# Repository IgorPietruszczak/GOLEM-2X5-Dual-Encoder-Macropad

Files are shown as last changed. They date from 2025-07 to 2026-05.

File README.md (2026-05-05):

# 🎮 GOLEM 2x5 Dual Encoder Macropad






An open-source 2x5 macropad featuring **dual rotary encoders**, a custom PCB, and fully 3D-printed case.



---

## ✨ Features

- **2×5 key grid** — 10 programmable keys
- **Dual rotary encoders** — for volume, scrolling, zoom, or any custom action
- **Pro Micro** microcontroller (ATmega32U4)
- **QMK firmware** — customizable layers, macros, and encoder mappings
- **Custom KiCad PCB** — open-source design files included
- **3D-printed case** — print-ready STL files included
- **MIT licensed** — free to use, modify, and share



---

## 📁 Repository Structure

```
GOLEM-2X5-Dual-Encoder-Macropad/
├── 3D Parts/                           # STL files for the case and knobs
├── Design Files For 3D Parts/          # KiCad schematics and PCB layout
├── PCB Design & Production files/      # Supporting design assets
├── QMK Keyboard Layout/                # QMK firmware source
├── LICENSE
└── README.md
```



---

## 🛒 Bill of Materials (BOM)

| Part | Quantity | Notes |
|---|---|---|
| Pro Micro (ATmega32U4) | 1 | USB-C version recommended |
| Rotary Encoder (EC11) | 2 | With push-button |
| Encoder Knobs | 2 | STL included, or use off-the-shelf |
| MX-compatible switches | 10 | 3-pin |
| 1N4148 Diodes | 10 | Through-hole |
| Keycaps | 10 | MX compatible |
| M2 screws 5mm & heat inserts | — | For case assembly |
| Custom PCB | 1 | Gerber files in `PCB Design & Production files/` |
| 3D-printed case | 1 set | STL files in `3D Parts/` |
| Silicone anti-slip pads | 4 | Placed in the corners on the bottom of the case |
| Tact Switch | 1 | For easy enabling of boot mode |



---

## 🖨️ 3D Printing

All STL files are located in the `3D Parts/` folder.

**Recommended settings:**
- Layer height: **0.2 mm**
- Infill: **15%**
- Supports: **No** (parts are designed to print without supports)
- Material: **PLA or PETG**

**Parts to print:**
- `Case_bottom.3mf` — Main keyboard body × 1
- `Encoder_Support.3mf` — Support to prevent bending the PCB while pressing the encoder button × 1
- `Knob_Edit_105_scaled.stl` — Knob for the standard rotary encoder × 2
- `PCB_Cover.stl` — Top PCB cover × 1

> The encoder knob model is adapted from [this Thingiverse design](https://www.thingiverse.com/thing:4206617/) — scaled up 5% to better fit EC11 encoders.

---

## 🔌 PCB & Wiring

PCB design files (KiCad) are located in the `PCB Design & Production files/` folder.
Ready Gerber files are located in the **production** folder.
Order PCB boards from the PCB manufacturer of your choosing.

**To open the project:**
1. Install [KiCad](https://www.kicad.org/) (version 7.0 or later recommended)
2. Open `Design_Files/*.kicad_pro`
3. Review the schematic

> KiCad component library courtesy of [@joe_scotto](https://www.youtube.com/@joe_scotto/featured) — this project is heavily inspired by this creator.

---

## 🔧 Assembly Guide

1. **Solder diodes to PCB** — Pay attention to soldering them with the correct polarity. Check the KiCad project or PCB 3D model for reference.
2. **Solder Pro Micro to PCB** — The project is designed to use the pin arrays that come with the microcontroller. Check the PCB 3D model for reference.
3. **Solder tact switch to PCB.**
4. **Place MX switches into holes on PCB Cover 3D print** — Pay attention to placing them in the correct orientation.
5. **Solder MX switches to PCB** — After this step the PCB cover is unremovable, so be sure to complete all prior steps correctly.
6. **Solder 2 rotary encoders to PCB** — Make sure they sit flat and stable before soldering.
7. **Insert heat inserts into designated places on Bottom Cover.**
8. **Screw PCB to bottom cover with M2 screws.**
9. **Place keycaps on MX switches and knobs on rotary encoders.**
10. **Stick silicone pads to the bottom of the Bottom Cover.**

---

## ⚡ Firmware Setup (QMK)

This keyboard uses QMK firmware. Here are some tutorials on how to set up the keyboard layout:

- [Tutorial 1](https://www.youtube.com/watch?v=fuBJbdCFF0Q&t=241s)
- [Tutorial 2](https://www.youtube.com/watch?v=hjml-K-pV4E&t=1155s)

### Quick Setup

1. **Install QMK Firmware** — QMK MSYS, QMK Toolbox, drivers, etc.
2. **Move the keyboard layout** from `QMK Keyboard Layout/` to your keyboards folder in QMK.
3. **Flash the GOLEM 2x5 keyboard layout using QMK Toolbox** — Enable flash mode using the tact switch on the keyboard.
4. **Edit the keyboard layout (optional)** — Open `golem_2x5_dualencoder_macropad/` in a text editor and edit the keyboard settings.

---

## 🤝 Contributing

Contributions are welcome! Feel free to:
- Open an **Issue** for bugs or suggestions
- Submit a **Pull Request** with improvements
- Share your build photos — I'd love to see them!

---

## 📄 License

This project is licensed under the **MIT License** — see the [LICENSE](LICENSE) file for details.

---

## 🙏 Credits

- Encoder knob 3D model by [Thingiverse user](https://www.thingiverse.com/thing:4206617/)
- KiCad component library by [@joe_scotto](https://www.youtube.com/@joe_scotto/featured)

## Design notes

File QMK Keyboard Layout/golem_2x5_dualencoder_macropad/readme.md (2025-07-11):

# golem_2x5_dualencoder_macropad

golem_2x5_dualencoder_macropad

*A short description of the keyboard/project*

* Keyboard Maintainer: [Igor Pietruszczak](https://github.com/IgorPietruszczak)
* Hardware Supported: *The PCBs, controllers supported*
* Hardware Availability: *Links to where you can find this hardware*

Make example for this keyboard (after setting up your build environment):

    make golem_2x5_dualencoder_macropad:default

Flashing example for this keyboard:

    make golem_2x5_dualencoder_macropad:default:flash

See the [build environment setup](https://docs.qmk.fm/#/getting_started_build_tools) and the [make instructions](https://docs.qmk.fm/#/getting_started_make_guide) for more information. Brand new to QMK? Start with our [Complete Newbs Guide](https://docs.qmk.fm/#/newbs).

## Bootloader

Enter the bootloader in 3 ways:

* **Bootmagic reset**: Hold down the key at (0,0) in the matrix (usually the top left key or Escape) and plug in the keyboard
* **Physical reset button**: Briefly press the button on the back of the PCB - some may have pads you must short instead
* **Keycode in layout**: Press the key mapped to `QK_BOOT` if it is available

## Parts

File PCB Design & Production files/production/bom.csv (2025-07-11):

Designator | Footprint | Quantity | Value | LCSC Part #
D1, D10, D11, D12, D2, D3, D4, D5, D6, D7, D8, D9 | Diode_DO-35 | 12 | D
S1, S10, S2, S3, S4, S5, S6, S7, S8, S9 | SW_Cherry_MX_1.00u_PCB | 10 | Keyswitch
SW1 | SW_TH_Tactile_Omron_B3F-10xx | 1 | SW_DPST_x2
SW2, SW3 | RotaryEncoder_Alps_EC11E-Switch_Vertical_H20mm | 2 | RotaryEncoder_Switch
U1 | Arduino_Pro_Micro | 1 | Arduino_Pro_Micro

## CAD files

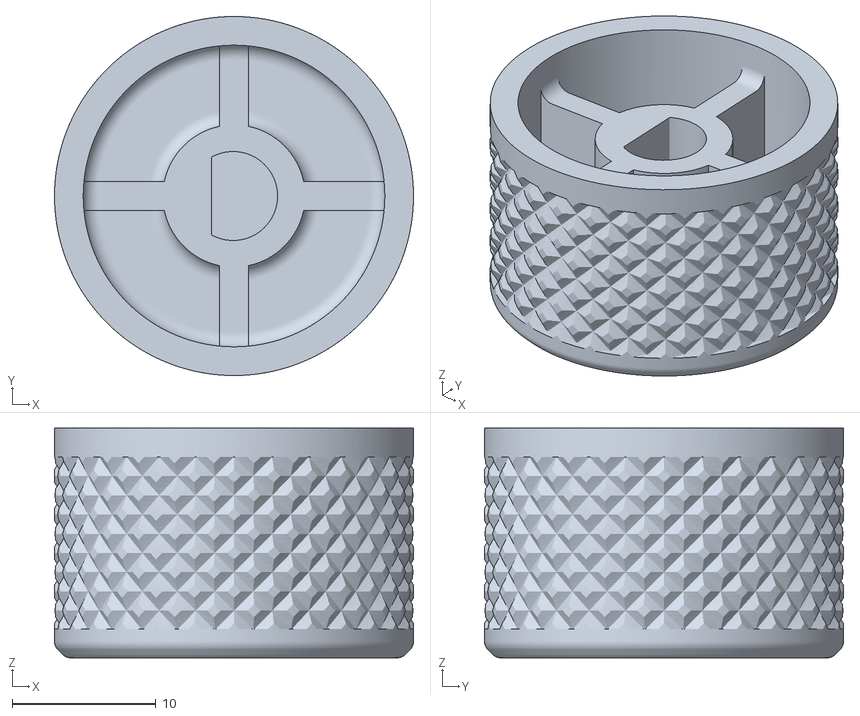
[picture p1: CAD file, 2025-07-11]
3D Parts/Knob_Edit_105_scaled.stl
25.0 x 25.0 x 16.0

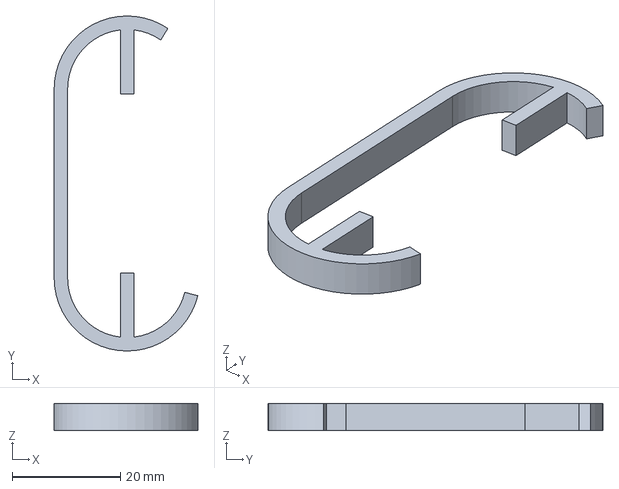
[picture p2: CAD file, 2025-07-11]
Design Files For 3D Parts/Case_Bottom+Support.FCStd
26.6 x 62.0 x 5.00 mm

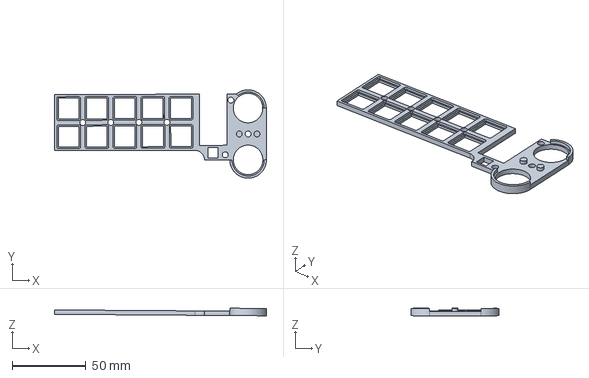
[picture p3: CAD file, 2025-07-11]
Design Files For 3D Parts/PCB_Cover.FCStd
143.7 x 59.9 x 5.18 mm

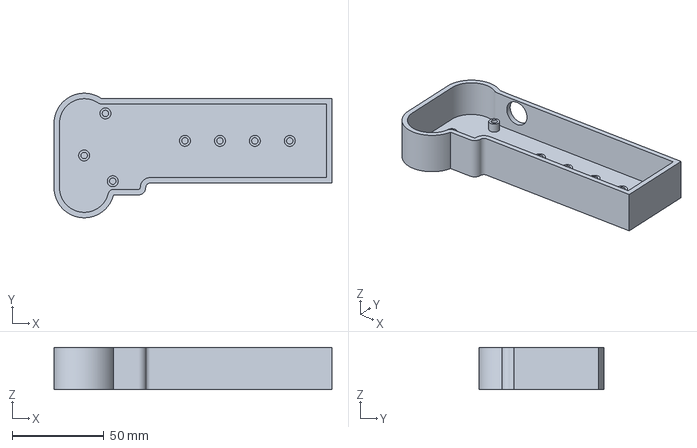
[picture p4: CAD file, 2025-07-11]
3D Parts/Case_bottom.3mf
151.7 x 68.0 x 23.0 mm

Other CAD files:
3D Parts/Encoder_Support.3mf
3D Parts/PCB_Cover.stl

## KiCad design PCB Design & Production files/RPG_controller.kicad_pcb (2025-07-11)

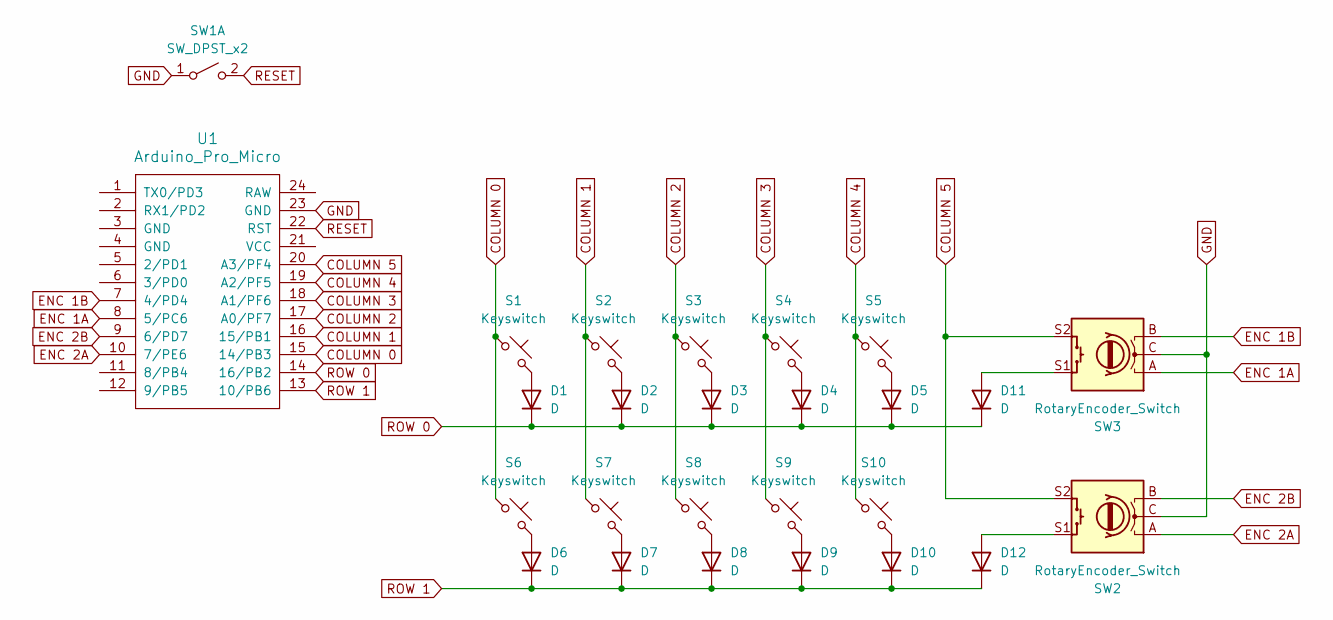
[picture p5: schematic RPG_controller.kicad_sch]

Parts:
D1, D2, D3, D4, D5, D6, D7, D8, D9, D10, D11, D12: D; Diode_DO-35
S1, S2, S3, S4, S5, S6, S7, S8, S9, S10: Keyswitch; SW_Cherry_MX_1.00u_PCB
SW1: SW_DPST_x2; SW_TH_Tactile_Omron_B3F-10xx
SW2, SW3: RotaryEncoder_Switch; RotaryEncoder_Alps_EC11E-Switch_Vertical_H20mm
U1: Arduino_Pro_Micro

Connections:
COLUMN 0: S1.1, S6.1, U1.15 (14/PB3)
COLUMN 1: S2.1, S7.1, U1.16 (15/PB1)
COLUMN 2: S3.1, S8.1, U1.17 (A0/PF7)
COLUMN 3: S4.1, S9.1, U1.18 (A1/PF6)
COLUMN 4: S5.1, S10.1, U1.19 (A2/PF5)
COLUMN 5: SW2.S2, SW3.S2, U1.20 (A3/PF4)
ENC 1A: SW3.A, U1.8 (5/PC6)
ENC 1B: SW3.B, U1.7 (4/PD4)
ENC 2A: SW2.A, U1.10 (7/PE6)
ENC 2B: SW2.B, U1.9 (6/PD7)
GND: SW1.1 (A), SW2.C, SW3.C, U1.23 (GND)
unnamed: D1.2 (A), S1.2
unnamed: D2.2 (A), S2.2
unnamed: D3.2 (A), S3.2
unnamed: D4.2 (A), S4.2
unnamed: D5.2 (A), S5.2
unnamed: D6.2 (A), S6.2
unnamed: D7.2 (A), S7.2
unnamed: D8.2 (A), S8.2
unnamed: D9.2 (A), S9.2
unnamed: D10.2 (A), S10.2
unnamed: D11.2 (A), SW3.S1
unnamed: D12.2 (A), SW2.S1
RESET: SW1.2 (B), U1.22 (RST)
ROW 0: D1.1 (K), D2.1 (K), D3.1 (K), D4.1 (K), D5.1 (K), D11.1 (K), U1.14 (16/PB2)
ROW 1: D6.1 (K), D7.1 (K), D8.1 (K), D9.1 (K), D10.1 (K), D12.1 (K), U1.13 (10/PB6)

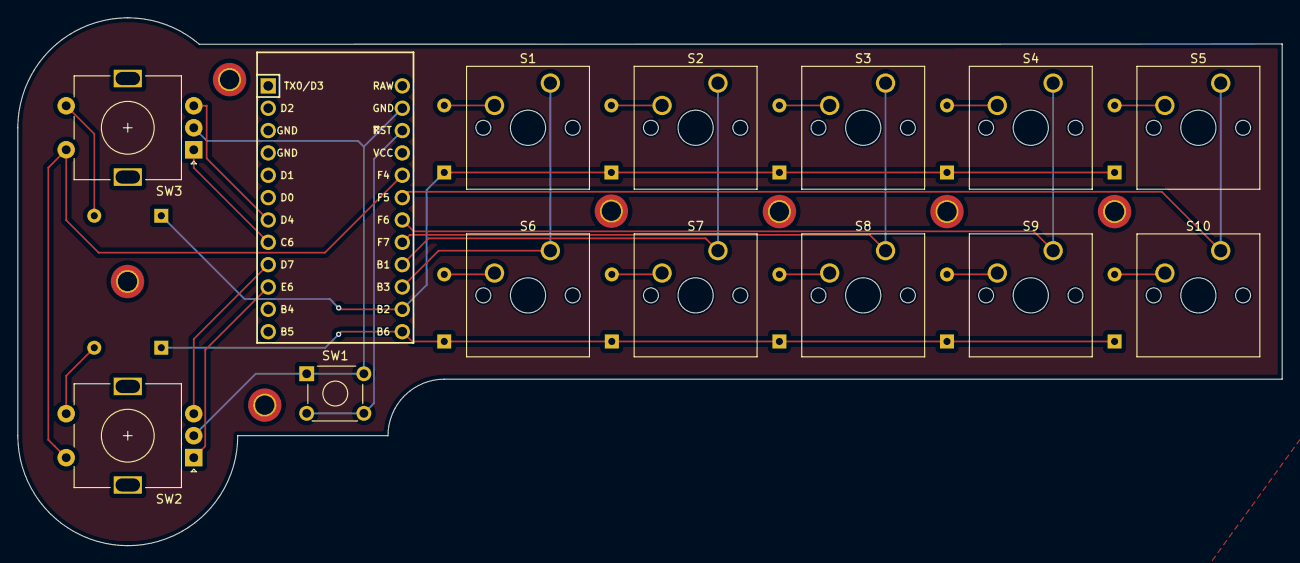
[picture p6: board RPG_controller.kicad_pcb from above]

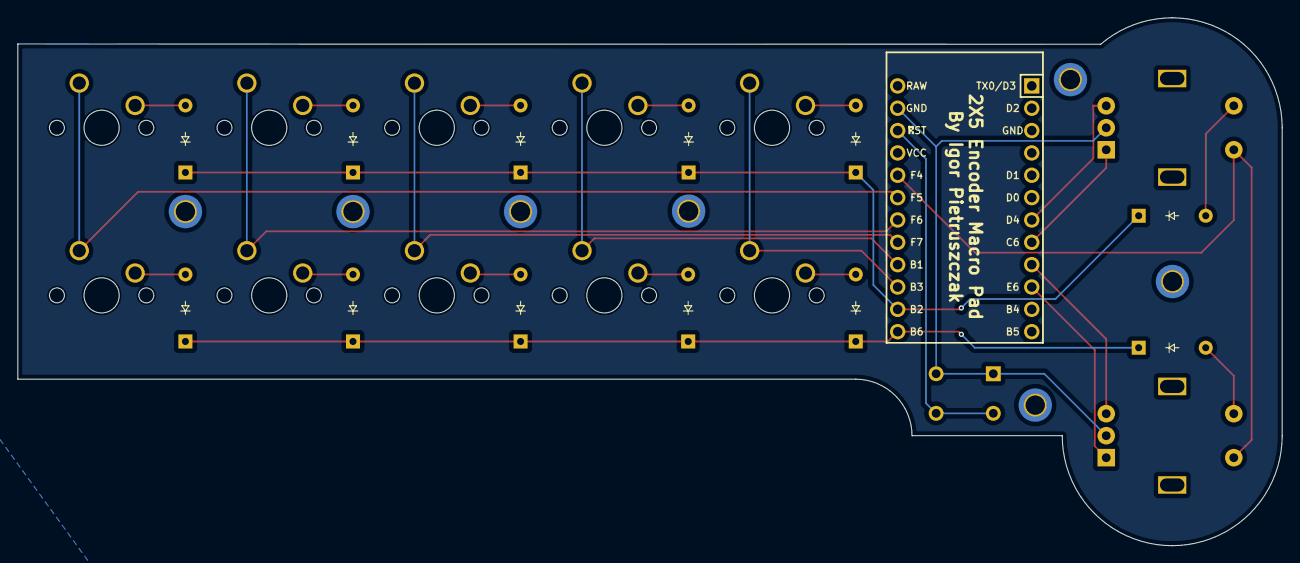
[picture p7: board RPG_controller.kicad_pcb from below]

Board: 2 copper layers, 143.7 x 60.0 mm, 26 parts (12 on the bottom side), 26 nets.

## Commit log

2025-07-11 Project files upload
    [Case_Bottom+Support.FCStd, Case_bottom.3mf, Encoder_Support.3mf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]
2026-05-05 Fixing organization and folder structure
    [Case_Bottom+Support.FCStd, PCB_Cover.3mf, PCB_Cover.FCStd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]

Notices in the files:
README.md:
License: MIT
